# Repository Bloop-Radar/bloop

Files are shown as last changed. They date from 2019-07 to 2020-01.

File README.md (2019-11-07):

# Bloop Radar Platform

**Note: Hardware is still under heavy development. Please use at your own risk.**

## What is Bloop?
Bloop is an open-source 24 GHz radar platform aimed to be an easy way for hobbyists, students, and engineers to learn and experiment with radar. 

The goal for this project is not to make an application-specific radar but instead create a flexible platform to learn more about doppler and FMCW radar principles. In order to accomplish this the hardware must be low cost, modular, and allow people to develop their own applications easily. 

Currently, the software solution for Bloop is still unknown as the hardware is still being developed. The plan is to use the ECP5 as the FPGA for this platform and open-source FPGA toolchains available such as [Yosys](https://github.com/YosysHQ/yosys) and [nextpnr](https://github.com/YosysHQ/nextpnr).

## Hardware
The hardware will consist of three modules: an **antenna module** (work in progress), **RF module** ([BGT24 Module](#bgt24-module---rev-a)), and **digital module** (work in progress).

### Planned Hardware Specifications 
* 24 GHz Transceiver MMIC ([BGT24MTR12](https://www.infineon.com/cms/en/product/sensor/radar-image-sensors/radar-sensors/radar-sensors-for-consumer-and-iot/bgt24mtr12/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))
  * 1 TX SMP Connector
  * 2 RX SMP Connectors
* PLL with chirp generation ([LMX2491](http://www.ti.com/product/LMX2491))
* 4 Channel ADC ([ADAR7251](https://www.analog.com/en/products/adar7251.html#))
* ECP5 FPGA
* USB
* ... and more TBD

### BGT24 Module - Rev A
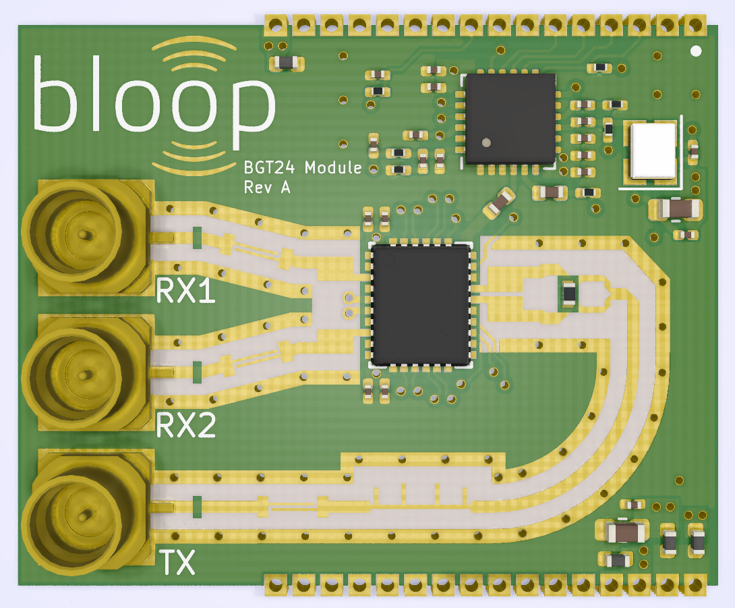
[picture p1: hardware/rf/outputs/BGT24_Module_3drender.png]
BGT24_Module_3drender
  

The BGT24 Module is the RF module for the Bloop radar platform, which provides differential I/Q data for RX1 and RX2 along with SPI and modulation control for the LMX2491 PLL and BGT24MTR12 RF transceiver. 

This module will continue to evolve as we test with the SPI Control prototyping hardware and develop some PCB antennas to test with.  

## Prototyping Hardware
Hardware found under `hardware/prototypes` is solely used to develop/evaluate the function of the RF section, BGT24 module, and the ADAR7251 ADC.

### SPI Control - Rev A
Work In Progress under branch `spi_control`  

The SPI Control hardware will include a USB-SPI controller for evaluating the BGT24 Module and ADC. The board will also include an external connector to interface with FPGA development boards.

### RF Front-End - Rev A
The RF Front-End is a panel of various RF microstrip structures to be evaluated for the RF section.

## License
Bloop hardware is distributed under the [Creative Commons Attribution Share Alike 4.0 International](LICENSE.txt)

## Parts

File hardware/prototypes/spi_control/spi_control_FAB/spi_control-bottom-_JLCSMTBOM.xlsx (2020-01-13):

Comment | Designator | Footprint | Description
100n | C21, C33, C37, C38, C39, C40, C42, C43 | C_0402_1005Metric | CAP CER 0.1UF 6.3V X5R 0402
1n | C44 | C_0402_1005Metric | CAP CER 1000PF 50V X7R 0402
100p | C1 | C_0402_1005Metric | CAP CER 100PF 50V C0G/NP0 0402
10u | C22, C28, C30, C32, C34, C35, C36 | C_0402_1005Metric | CAP CER 10UF 6.3V X6S 0402
12p | C18, C23 | C_0402_1005Metric | CAP CER 12PF 50V C0G/NP0 0402
1u | C3, C19 | C_0402_1005Metric | CAP CER 1UF 6.3V X5R 0402
390p | C29 | C_0402_1005Metric | CAP CER 390PF 50V X7R 0402
4.7u | C2, C4 | C_0402_1005Metric | CAP CER 4.7UF 6.3V X5R 0402
5.6n | C27 | C_0402_1005Metric | CAP CER 5600PF 25V X7R 0402
10k | R9, R11, R12 | R_0402_1005Metric | RES SMD 10K OHM 1% 1/16W 0402
1k | R4, R10 | R_0402_1005Metric | RES SMD 1K OHM 1% 1/16W 0402
1M | R1 | R_0402_1005Metric | RES SMD 1M OHM 1% 1/16W 0402
330 | R3, R8 | R_0402_1005Metric | RES SMD 330 OHM 1% 1/16W 0402
820 | R2 | R_0402_1005Metric | RES SMD 820 OHM 5% 1/16W 0402
SP0503BAHTG | D1 | SOT-143 | TVS DIODE 5.5V 8.5V SOT143-4
MCP2210-I_MQ | U3 | QFN-20-1EP_5x5mm_P0.65mm_EP3.35x3.35mm | IC CONVERTER USB-SPI 20-QFN
ST1L08SPU33R | U2 | DFN-8-1EP_2x3mm_P0.5mm_EP0.61x2.2mm | IC REG LINEAR 3.3V 800MA 8DFN
12MHZ | Y1 | Crystal_SMD_Abracon_ABM8G-4Pin_3.2x2.5mm | CRYSTAL 12MHZ 12PF SMD
1k | FB1, FB2 | L_0603_1608Metric | FERRITE BEAD 1 KOHM 0603 1LN
Versa_2 | J2 | PinSocket_2x20_P2.54mm_Vertical_SMD | CONN HDR 40POS 0.1 TIN SMD
Versa_1 | J3 | PinSocket_2x20_P2.54mm_Vertical_SMD | CONN HDR 40POS 0.1 TIN SMD
USB_B_Micro | J1 | USB_Micro-B_Molex_47346-0001 | CONN RCPT USB2.0 MICRO B SMD R/A

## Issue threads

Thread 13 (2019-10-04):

Select and implement low noise power circuit on SPI controller prototype

leoleal3, 2019-10-04:
Need to find a low noise LDO for 3.3V output for the PLL and RF MMIC

leoleal3, 2019-10-13:
Selected and implemented ST1L08SPU33R for the SPI controller prototype board in 42bd93bd553da56d5092573edd4d9227b1fe1c8b.
In the future I think we will want separate LDOs for specific parts.

Closed 2019-10-13.

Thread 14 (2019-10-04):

Select and implement SPI controller for SPI_controller prototype

leoleal3, 2019-10-04:

leoleal3, 2019-10-13:
Selected MCP2210-L/MQ and implemented in schematic here: ad3a562a2b1e13b54f219fbda9ca29bfedb54d95

Closed 2019-10-13.

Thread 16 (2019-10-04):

Design LMX2491 PLL loop filter

roguepengu1n, 2019-10-04:

roguepengu1n, 2019-11-04:
For now, we are going to use the loop filter part values used in the [Infineon Position2Go](https://www.infineon.com/cms/en/product/evaluation-boards/demo-position2go/). During testing of the module, we can experiment with changing values based on the [TI PLLatinum simulation tool](http://www.ti.com/tool/PLLATINUMSIM-SW).

Closed 2019-11-04.

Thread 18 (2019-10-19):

Select a connector for the external IO on the SPI control board

roguepengu1n, 2019-10-19:
Need a connector to interface with the ADC and allow the use of external FPGA/SoC dev boards to interface with. Possibly a PMOD interface?

roguepengu1n, 2019-11-11:
Going with two 2x20 female 2.54mm pin headers that will interface with the [ECP5 Evaluation Board](http://www.latticesemi.com/ecp5-evaluation) Vera Header from Lattice.

Closed 2019-11-11.

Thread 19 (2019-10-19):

Add BGT24 Module symbol and footprint

roguepengu1n, 2019-10-19:
Need a symbol and footprint for the BGT24 Module revA board to use in the SPI control board

roguepengu1n, 2019-11-04:
Added symbol and footprint in 3aa3cebe3509e6f3966daaffc69ec17ca2079d38

Closed 2019-11-04.

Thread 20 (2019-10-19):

SPI control board layout

roguepengu1n, 2019-10-19:
Layout of the SPI control prototyping board

roguepengu1n, 2019-11-18:
Layout completed by @kishan118 a3565c40fd2059d0a1c43607e4b8c9b3cc40f425.
Review of layout to be completed next.

Closed 2019-11-18.

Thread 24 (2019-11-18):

SPI_Control Layout Review

roguepengu1n, 2019-11-18:
Review conducted on spi_control commit a3565c40fd2059d0a1c43607e4b8c9b3cc40f425.

**Findings from review to be implemented:**

1. Remove "dime for scale" from ECO layer.
2. Fill on Top layer has no net, set to GND.
3. Fill on Bottom layer has no net set to GND.
4. Schematic: Clean up the ground connections on J40, J39, Y2, and Y1.
5. Schematic: Remove ECP5 eval board schematic image.
6. Need to generate HTML BOM.
7. Schematic: Add NC to J1 and J2 where needed.
8. Change directory “gerbers” to “spi_control_FAB”
9. Add 3d model for Y1?
10. Add vias to isolated island fills.
11. Add higher-priority zone for U3.
12. Add pin one indicators to J39 and J40 silkscreen.
13. Double-check via annular ring; does it support JLC’s fab requirements?
14. Center layout in .kicad_pcb file.
15. Add “Rev A” to silkscreen.
16. Use the /lib/bloop.kicad_wks file for the .kicad_pcb file.
17. Add LED silkscreen labels.
18. Add standoffs to schematic (to be tracked by BOM).
19. Add OSHW logo.
20. Set mounting holes to GND.
21. Schematic: Add typical current draw for ADAR7251 and maybe BG24 Module.
22. Select Ferrite bead MPNs
23. Try to condense MPNs to common MPNs across BGT24 module (reference: bloop/hardware/rf/bom)
24. Schematic: move dashed line box over ADC input filter caps to right so that it doesn’t interfere with labels. Change comment to “Redundant filtering if necessary” or something.
25. Generate PDF output files of schematic and PCB.

**Additional Notes:**
- Consider alignment pin in order to keep the BGT24 module aligned with the SPI board and antenna board.
- BGT24 Module 3d model is crooked. Will fix in: https://github.com/Bloop-Radar/bloop/issues/23

Closed 2020-01-05.

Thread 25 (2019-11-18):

Tent vias in BGT24 Module FAB files

roguepengu1n, 2019-11-18:
Vias should be tented with mask on BGT24 Module to prevent shorts on base-board that it mates with.

Closed 2019-11-21.

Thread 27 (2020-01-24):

Incorrect footprint for U2 ST1L08SPU33R on SPI Control Board Rev A

roguepengu1n, 2020-01-24:
Current footprint is: Package_DFN_QFN:DFN-8-1EP_2x3mm_P0.5mm_EP0.61x2.2mm
Should be: Package_DFN_QFN:DFN-8-1EP_3x2mm_P0.5mm_EP1.3x1.5mm

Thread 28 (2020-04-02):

Incorrect footprint for micro-USB connector J1 on SPI Control Board Rev A

roguepengu1n, 2020-04-02:
Footprint does not match the MPN footprint ([10118193-0001LF](https://www.amphenol-icc.com/media/wysiwyg/files/drawing/10118193.pdf)).
The footprint in the layout is a completely SMD footprint while the MPN has THT shield pins.

Change J1 footprint to correct MPN footprint.

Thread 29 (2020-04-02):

Add solder mask to TX and RX pads on BGT24MTR12 footprint

roguepengu1n, 2020-04-02:
To prevent solder from flowing along the transmission lines, add solder mask to spacing for pads 22, 23, 3, and 8.

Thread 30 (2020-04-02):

bloop.dcm causing warnings when opening schematics

roguepengu1n, 2020-04-02:
Error message appears when opening schematics:

```
9:28:18 PM: Symbol name conflict in library:
C:\Projects\bloop\hardware\prototypes\spi_control/../../lib/bloop.lib
'BGT24_Module_Castellations' has been renamed to 'BGT24_Module_Castellations_0'
9:28:18 PM: Symbol name conflict in library:
C:\Projects\bloop\hardware\prototypes\spi_control/../../lib/bloop.lib
'ECS-2520S' has been renamed to 'ECS-2520S_0'
9:28:18 PM: Symbol name conflict in library:
C:\Projects\bloop\hardware\prototypes\spi_control/../../lib/bloop.lib
'GNDRF' has been renamed to 'GNDRF_0'
9:28:18 PM: Alias 'KC3225K40' not found in library: 'C:\Projects\bloop\hardware\prototypes\spi_control\..\..\lib\bloop.dcm'

```

Most likely because bloop.dcm got added when the spi_control branch was merged.

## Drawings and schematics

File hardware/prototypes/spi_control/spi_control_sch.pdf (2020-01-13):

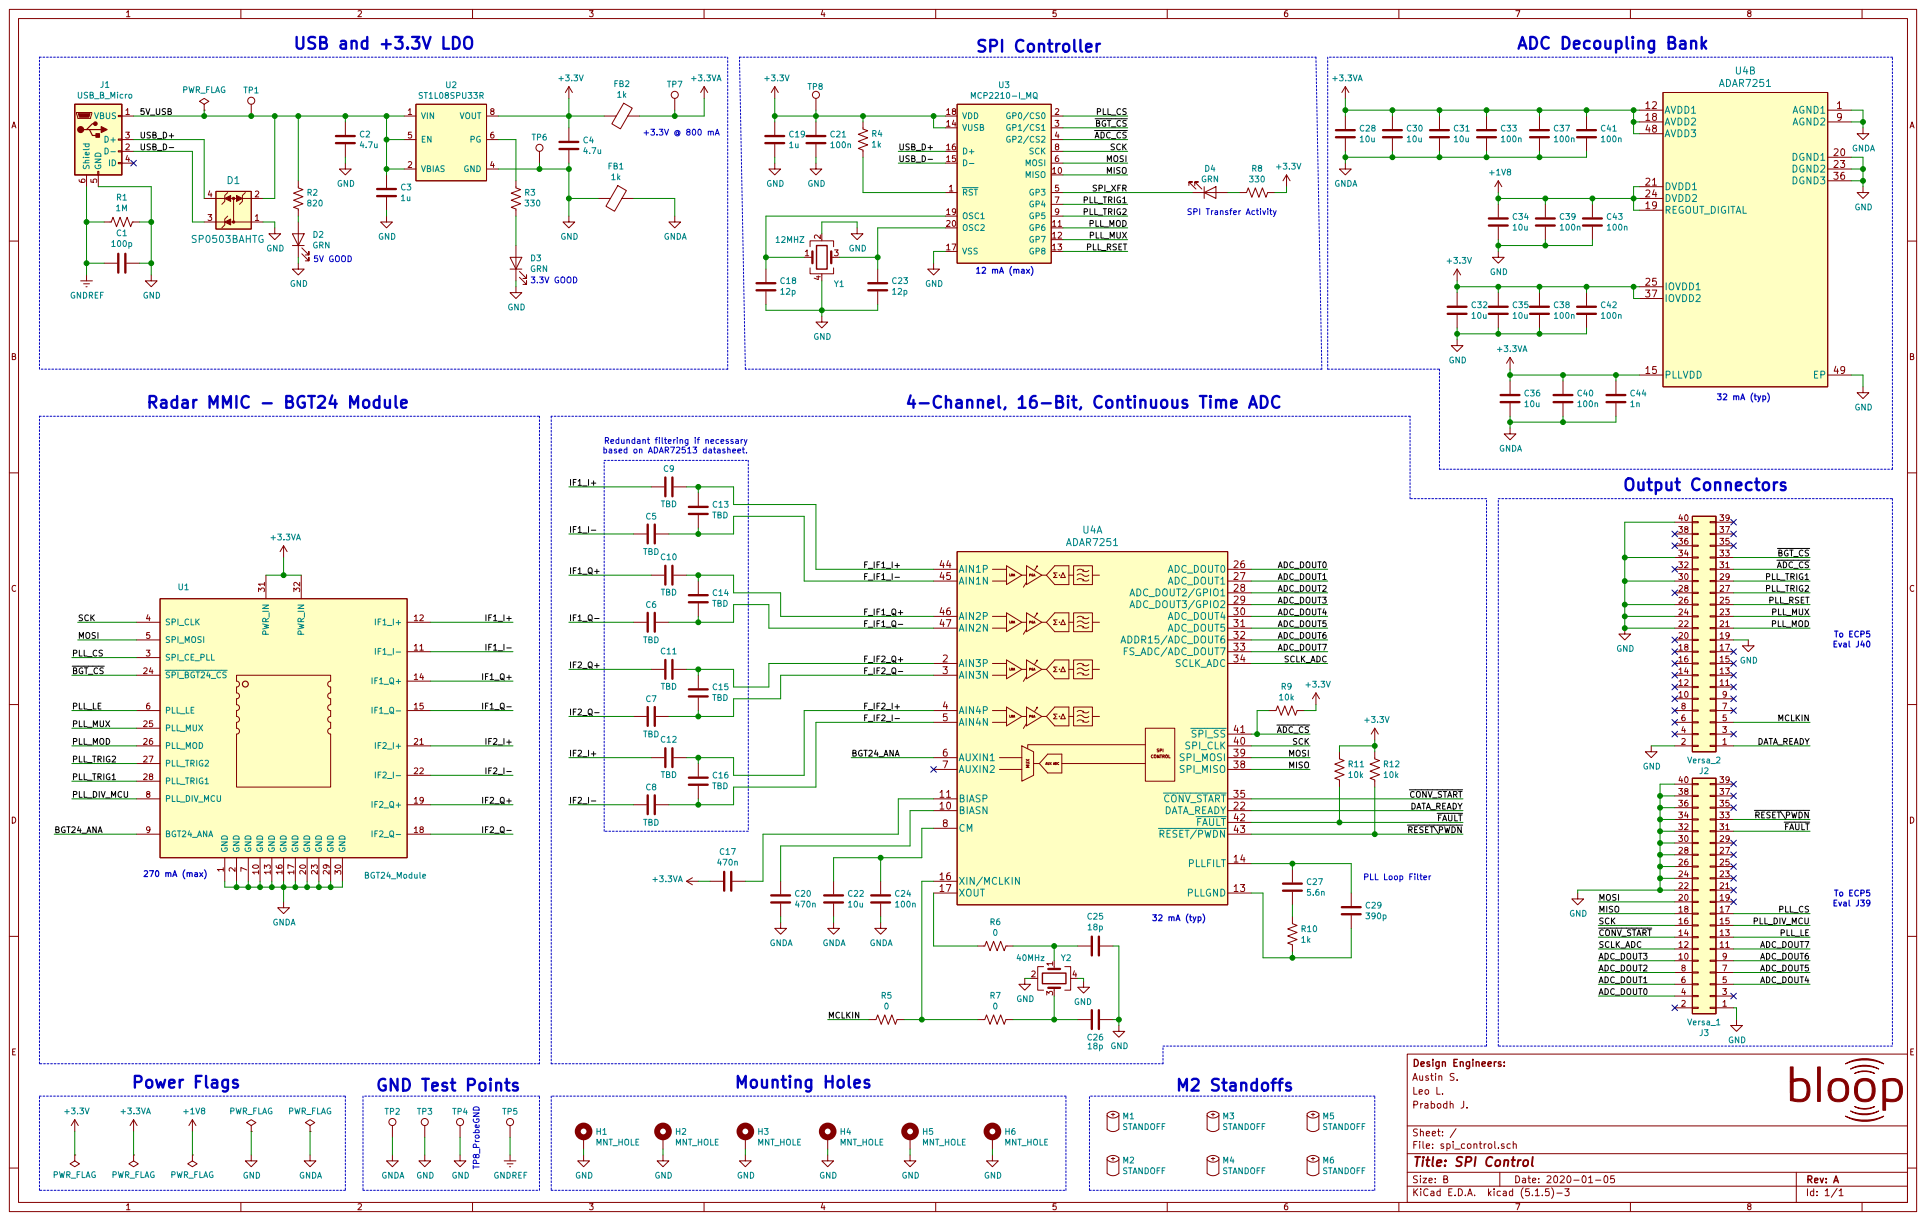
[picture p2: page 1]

4-Channel, 16-Bit, Continuous Time ADC

Redundant filtering if necessary based on ADAR72513 datasheet.
C9 TBD

ADAR7251
File: spi_control.sch Sheet: / Prabodh J. Leo L. Austin S. Design Engineers: R9

24 | 23 PLL_MUX
22 | 21

32 | 31
30 | 29 PLL_CS
28 | 27
26 | 25
24 | 23

Id: 1/1 Title: SPI Control

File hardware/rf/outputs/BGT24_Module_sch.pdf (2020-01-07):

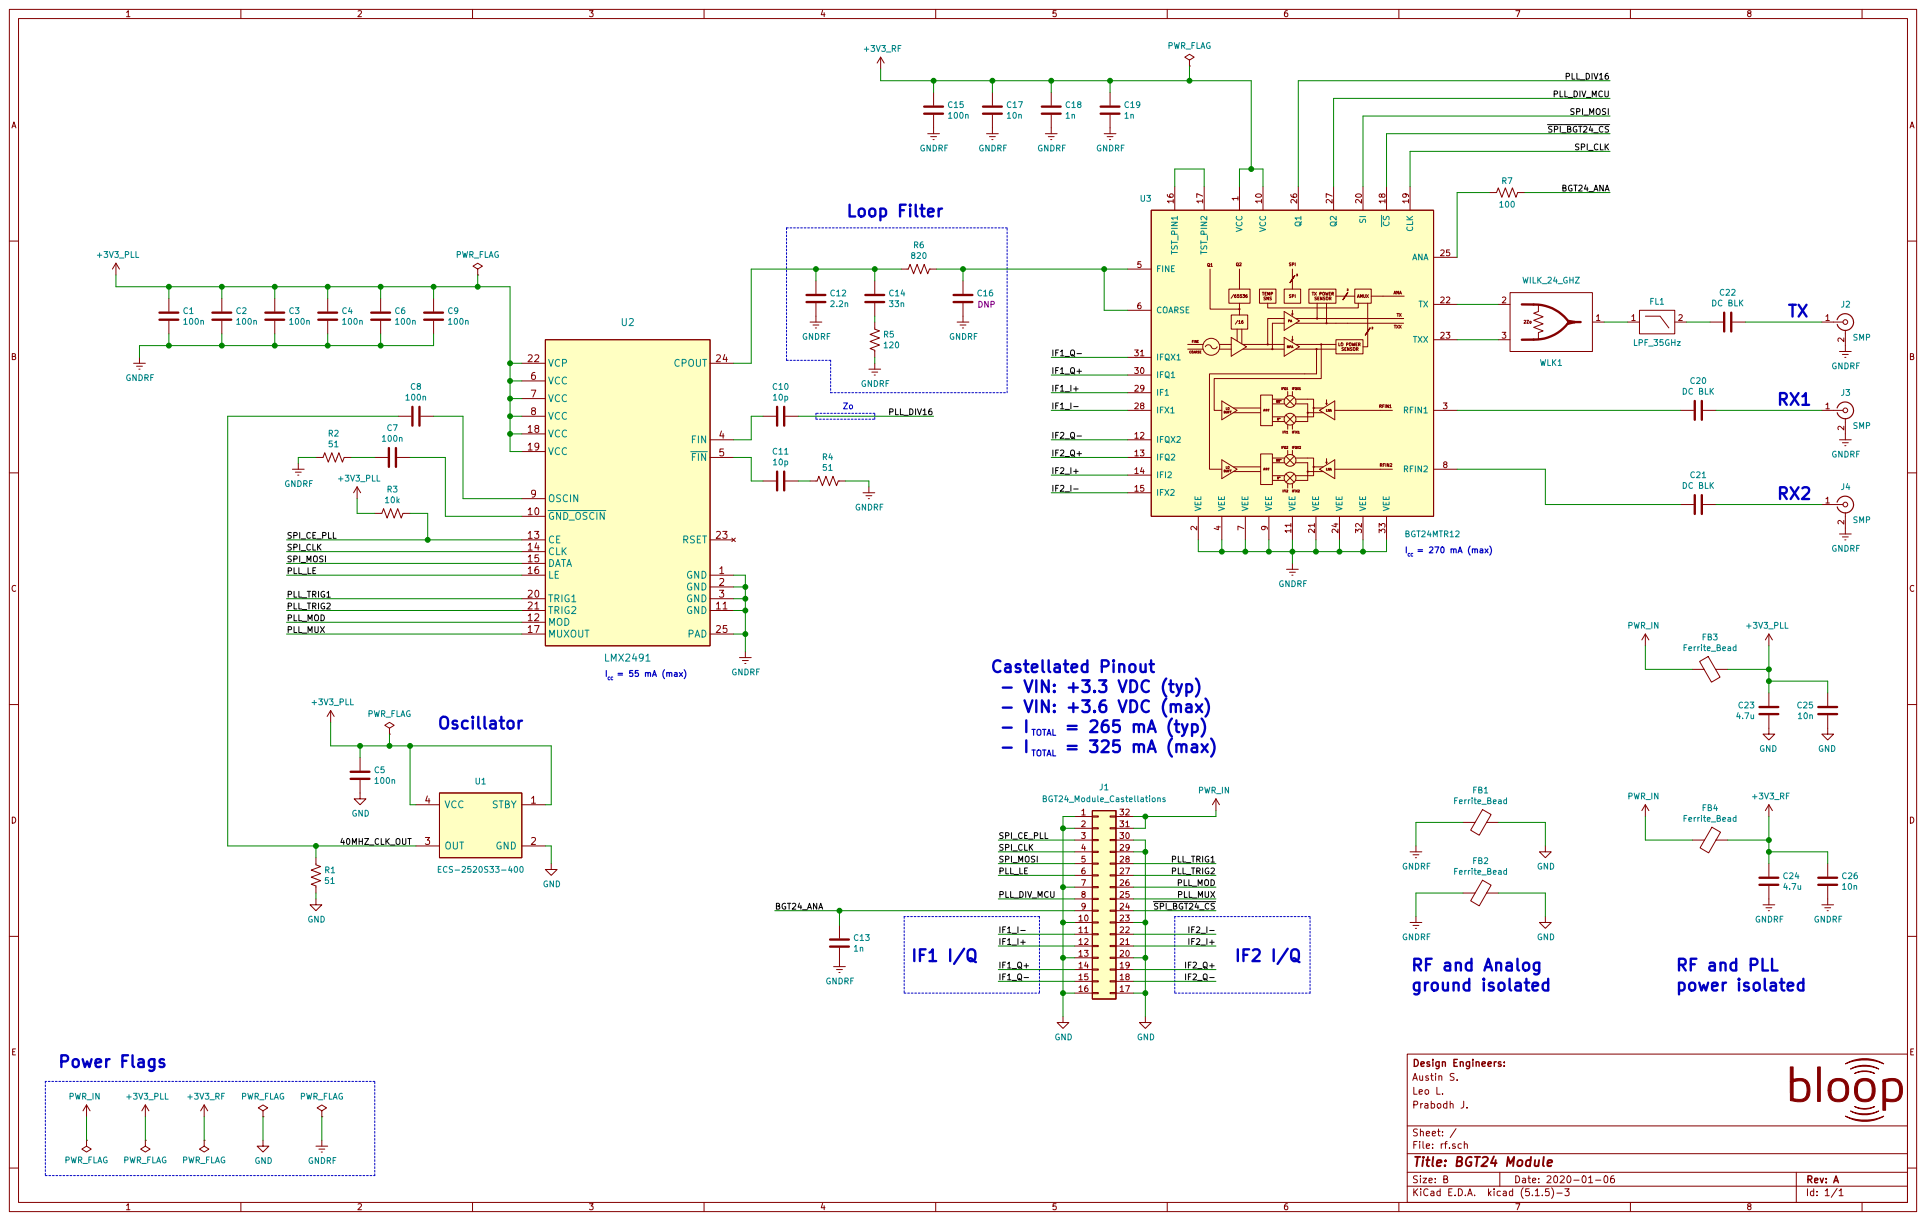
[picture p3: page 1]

2 SI 20 VEE 21 TX 22 TXX 23 VEE 24 ANA 25 Q1 26 Q2 27

LO POWER MPA

GNDRF GNDRF

2 | 31
3 4 5 6 7 | 30

10 | | 23
11 12 13 | | 22

21 | | IF2_I+
20 | | IF2_Q+

File: rf.sch Sheet: / Prabodh J. Leo L. Austin S. Design Engineers:

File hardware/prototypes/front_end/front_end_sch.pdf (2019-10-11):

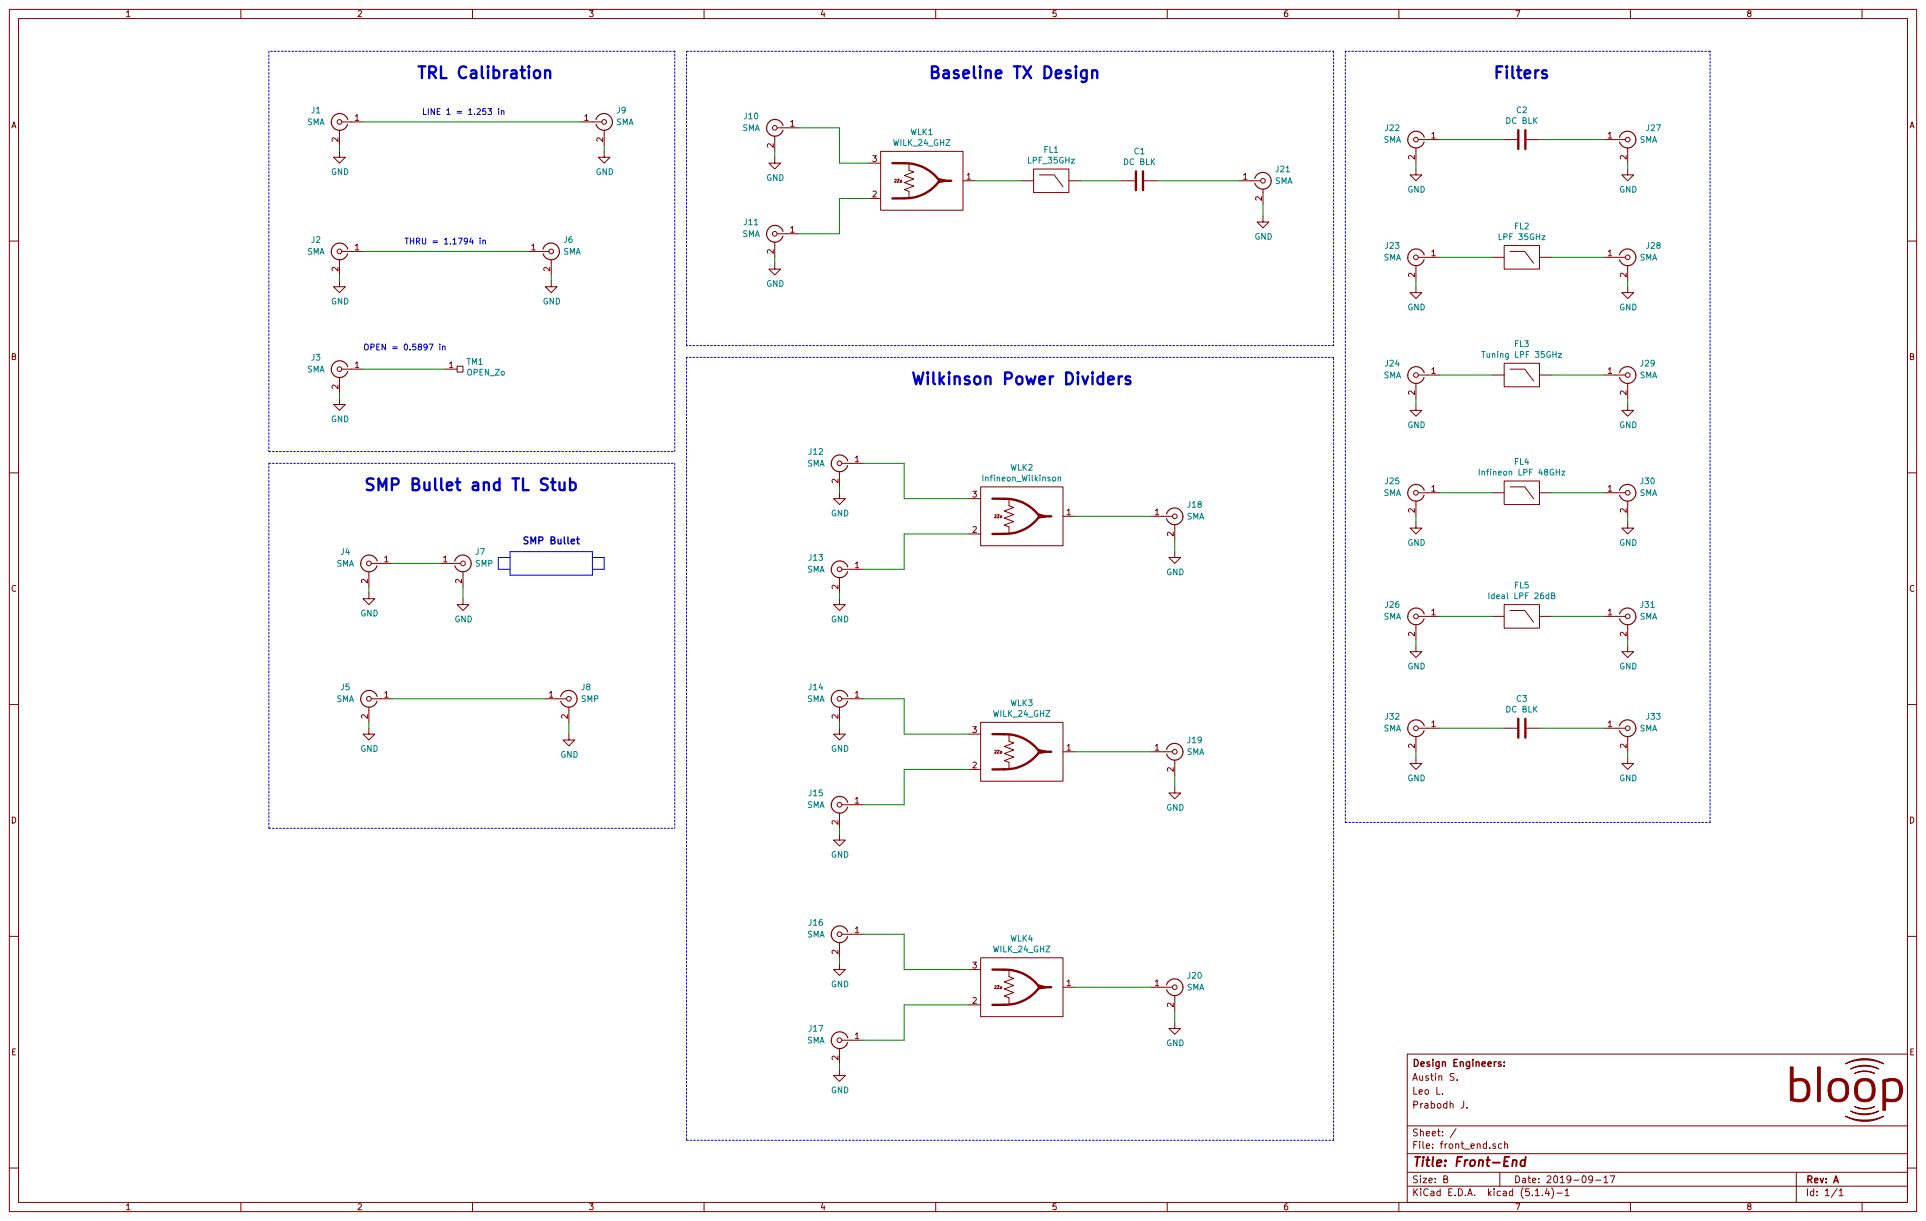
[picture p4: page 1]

LINE 1 = 1.253 in SMP Bullet and TL Stub
J3 SMA GND 1 2

File: front_end.sch Sheet: / Prabodh J. Leo L. Austin S. Design Engineers:

Id: 1/1 Title: Front-End

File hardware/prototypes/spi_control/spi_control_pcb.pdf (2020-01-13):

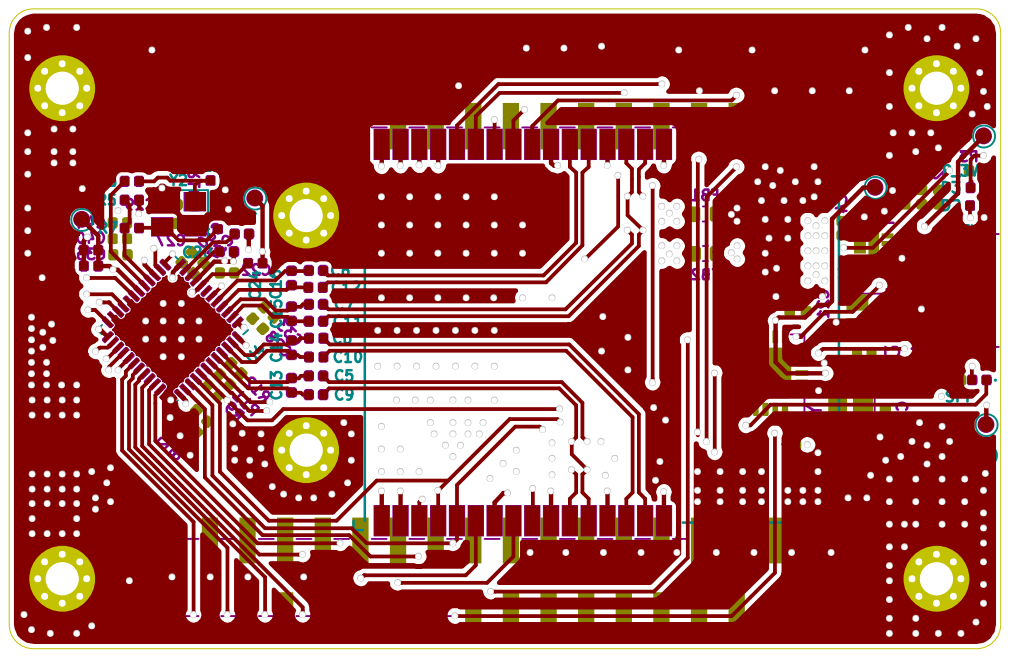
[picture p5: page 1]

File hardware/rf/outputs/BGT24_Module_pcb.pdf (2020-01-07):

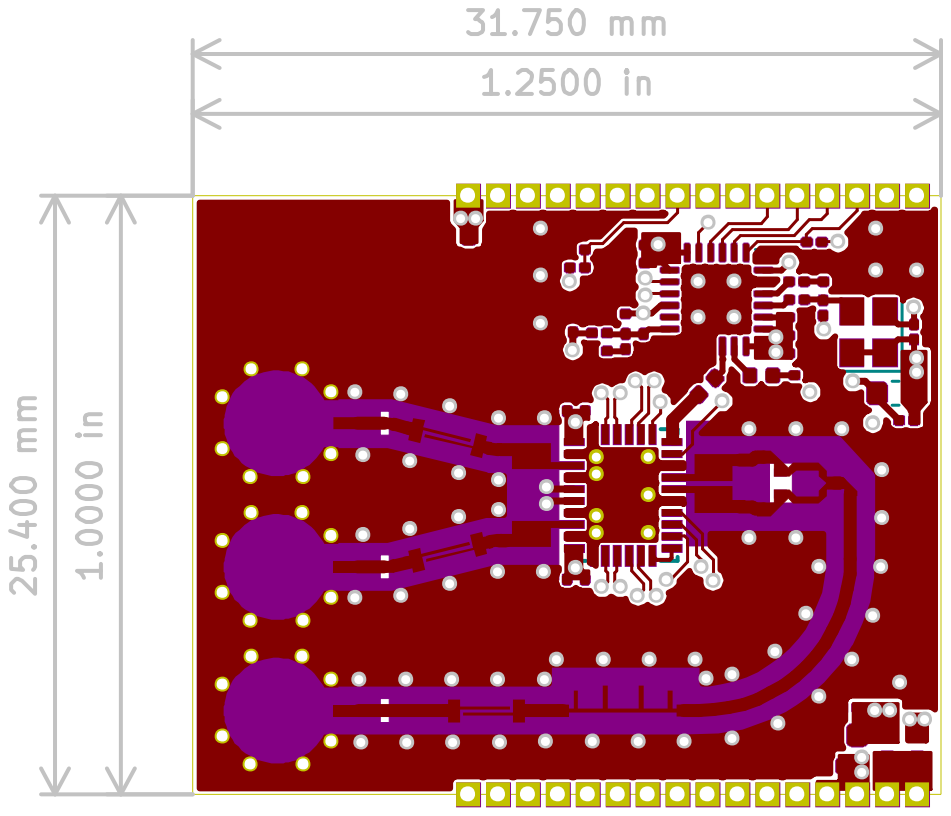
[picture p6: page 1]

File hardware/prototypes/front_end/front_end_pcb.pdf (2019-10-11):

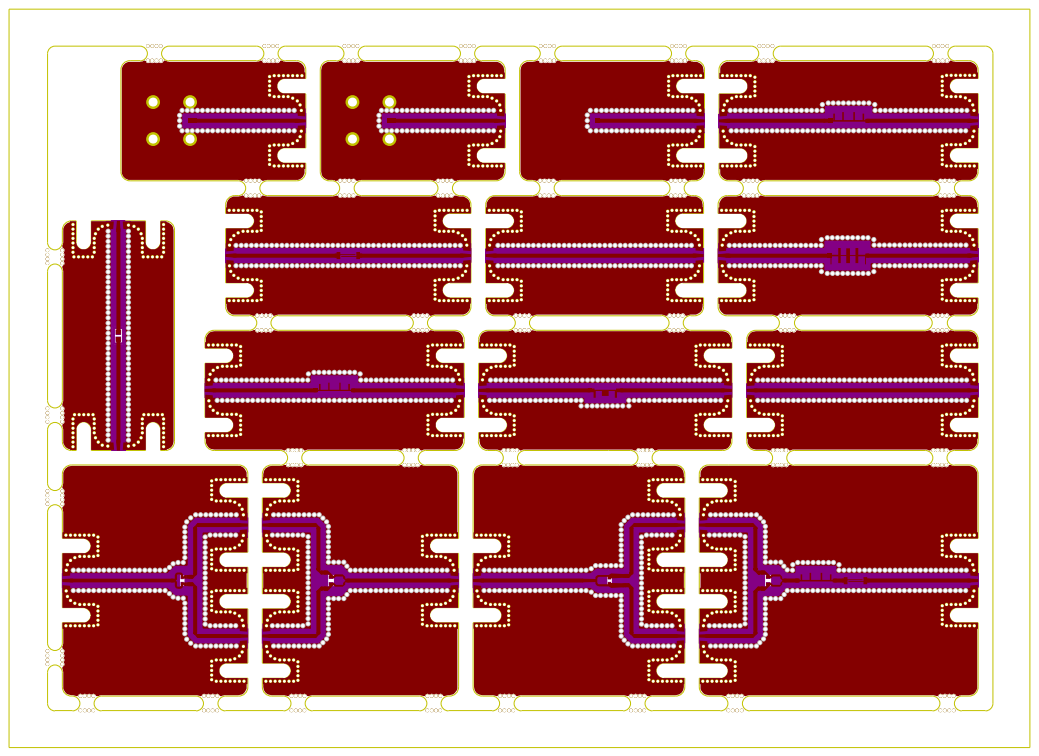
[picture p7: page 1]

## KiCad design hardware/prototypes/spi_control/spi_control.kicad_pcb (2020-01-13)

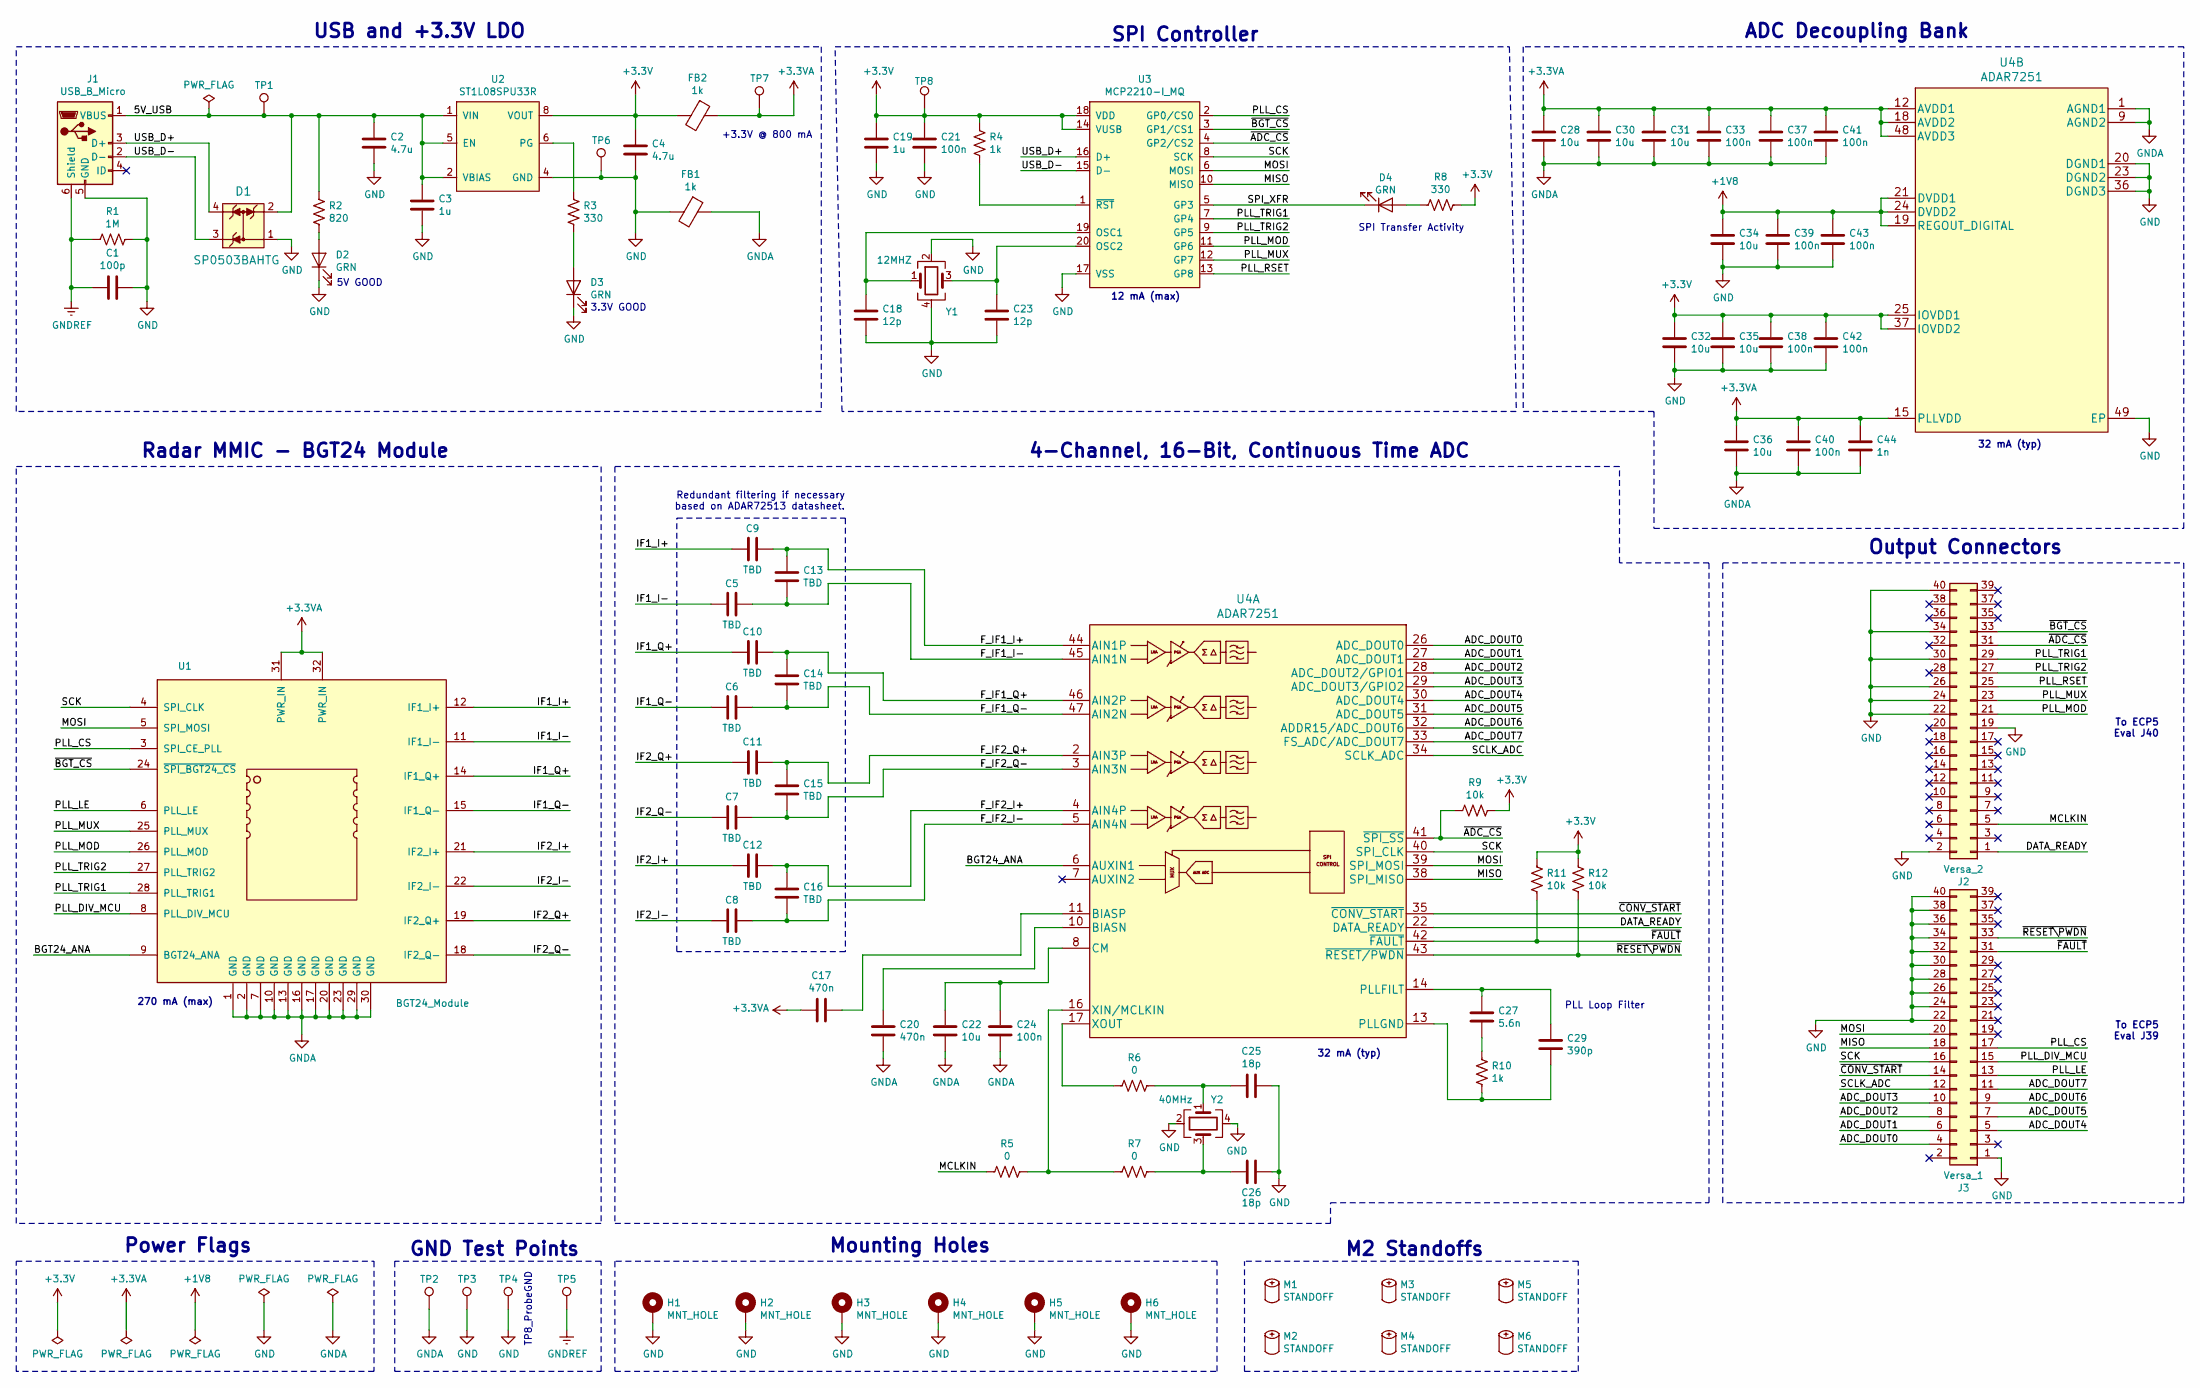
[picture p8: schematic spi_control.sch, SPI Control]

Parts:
C1: 100p; C_0402_1005Metric; MPN GCM1555C1H101JA16D; Digi-Key_PN 490-10669-1-ND
C2, C4: 4.7u; C_0402_1005Metric; MPN GRM155R60J475ME47D; Digi-Key_PN 490-5915-1-ND
C3, C19: 1u; C_0402_1005Metric; MPN CL05A105MQ5NNNC; Digi-Key_PN 1276-1235-1-ND
C5, C6, C7, C8, C9, C10, C11, C12, C13, C14, C15, C16: TBD; C_0402_1005Metric
C17, C20: 470n; C_0402_1005Metric; MPN CL05A474KQ5NNNC; Digi-Key_PN 1276-1479-1-ND
C18, C23: 12p; C_0402_1005Metric; MPN C0402C120J5GACTU; Digi-Key_PN 399-1013-1-ND
C21, C24, C33, C37, C38, C39, C40, C41, C42, C43: 100n; C_0402_1005Metric; MPN CL05A104KQ5NNNC; Digi-Key_PN 1276-1442-1-ND
C22, C28, C30, C31, C32, C34, C35, C36: 10u; C_0402_1005Metric; MPN GRM155C80J106ME11D; Digi-Key_PN 490-13233-1-ND
C25, C26: 18p; C_0402_1005Metric; MPN 04025A180JAT2A; Digi-Key_PN 478-1073-1-ND
C27: 5.6n; C_0402_1005Metric; MPN CL05B562KA5NNNC; Digi-Key_PN 1276-1578-1-ND
C29: 390p; C_0402_1005Metric; MPN CL05B391KB5NNNC; Digi-Key_PN 1276-1560-1-ND
C44: 1n; C_0402_1005Metric; MPN C0402C102K5RACTU; Digi-Key_PN 399-1032-1-ND
D1: SP0503BAHTG; SOT-143; MPN SP0503BAHTG; Digi-Key_PN F2715CT-ND
D2, D3, D4: GRN; LED_0402_1005Metric; MPN SML-P13PTT86R; Digi-Key_PN 846-1197-1-ND
FB1, FB2: 1k; L_0603_1608Metric; MPN 742792662; Digi-Key_PN 732-4670-1-ND
H1, H2, H3, H4, H5, H6: MNT_HOLE; MountingHole_2.2mm_M2_Pad_Via
J1: USB_B_Micro; USB_Micro-B_Molex_47346-0001; MPN 10118193-0001LF; Digi-Key_PN 609-4616-1-ND
J2: Versa_2; PinSocket_2x20_P2.54mm_Vertical_SMD; MPN NPTC202KFMS-RC; Digi-Key_PN S5690-ND
J3: Versa_1; PinSocket_2x20_P2.54mm_Vertical_SMD; MPN NPTC202KFMS-RC; Digi-Key_PN S5690-ND
M1, M2, M3, M4, M5, M6: STANDOFF; MPN 970120244; Digi-Key_PN 732-12852-ND
R1: 1M; R_0402_1005Metric; MPN RC0402FR-071ML; Digi-Key_PN 311-1.00MLRCT-ND
R2: 820; R_0402_1005Metric; MPN RC0402JR-07820RL; Digi-Key_PN 311-820JRCT-ND
R3, R8: 330; R_0402_1005Metric; MPN RC0402FR-07330RL; Digi-Key_PN 311-330LRCT-ND
R4, R10: 1k; R_0402_1005Metric; MPN RC0402FR-071KL; Digi-Key_PN 311-1.00KLRCT-ND
R5, R6, R7: 0; R_0402_1005Metric; MPN RC0402JR-070RL; Digi-Key_PN 311-0.0JRCT-ND
R9, R11, R12: 10k; R_0402_1005Metric; MPN RC0402FR-0710KL; Digi-Key_PN 311-10.0KLRCT-ND
TP1, TP2, TP3, TP5, TP6, TP7, TP8: TestPoint; TestPoint_Pad_D1.0mm
TP4: TestPoint; TestPoint_Keystone_5019_Minature; MPN 5019; Digi-Key_PN 36-5019CT-ND
U1: BGT24_Module
U2: ST1L08SPU33R; DFN-8-1EP_2x3mm_P0.5mm_EP0.61x2.2mm; MPN ST1L08SPU33R; Digi-Key_PN 497-15508-1-ND
U3: MCP2210-I_MQ; QFN-20-1EP_5x5mm_P0.65mm_EP3.35x3.35mm; MPN MCP2210-I/MQ; Digi-Key_PN MCP2210-I/MQ-ND
U4: ADAR7251; LFCSP-48-1EP_7x7mm_P0.5mm_EP4.1x4.1mm; MPN ADAR7251WBCSZ; Digi-Key_PN ADAR7251WBCSZ-ND
Y1: 12MHZ; Crystal_SMD_Abracon_ABM8G-4Pin_3.2x2.5mm; MPN ECS-120-12-33-AGN-TR; Digi-Key_PN XC2611CT-ND
Y2: 40MHz; Crystal_SMD_Abracon_ABM8G-4Pin_3.2x2.5mm; MPN ECS-400-18-33-JGN-TR; Digi-Key_PN XC2717CT-ND

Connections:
+1V8: C34.1, C39.1, C43.1, U4.19 (REGOUT_DIGITAL), U4.21 (DVDD1), U4.24 (DVDD2)
+3.3VA: C17.2, C28.1, C30.1, C31.1, C33.1, C36.1, C37.1, C40.1, C41.1, C44.1, FB2.1, TP7.1, U1.31 (PWR_IN), U1.32 (PWR_IN), U4.12 (AVDD1), U4.15 (PLLVDD), U4.18 (AVDD2), U4.48 (AVDD3)
+3V3: C4.1, C19.1, C21.1, C32.1, C35.1, C38.1, C42.1, FB2.2, R4.2, R8.1, R9.1, R11.1, R12.1, TP8.1, U2.8 (VOUT), U3.14 (VUSB), U3.18 (VDD), U4.25 (IOVDD1), U4.37 (IOVDD2)
/5V_USB: C2.1, C3.1, D1.2, J1.1 (VBUS), R2.2, TP1.1, U2.1 (VIN), U2.2 (VBIAS), U2.5 (EN)
/ADC_DOUT0: J3.4, U4.26 (ADC_DOUT0)
/ADC_DOUT1: J3.6, U4.27 (ADC_DOUT1)
/ADC_DOUT2: J3.8, U4.28 (ADC_DOUT2/GPIO1)
/ADC_DOUT3: J3.10, U4.29 (ADC_DOUT3/GPIO2)
/ADC_DOUT4: J3.5, U4.30 (ADC_DOUT4)
/ADC_DOUT5: J3.7, U4.31 (ADC_DOUT5)
/ADC_DOUT6: J3.9, U4.32 (ADDR15/ADC_DOUT6)
/ADC_DOUT7: J3.11, U4.33 (FS_ADC/ADC_DOUT7)
/BGT24_ANA: U1.9 (BGT24_ANA), U4.6 (AUXIN1)
/DATA_READY: J2.1, U4.22 (DATA_READY)
/F_IF1_I+: C9.2, C13.2, U4.44 (AIN1P)
/F_IF1_I-: C5.2, C13.1, U4.45 (AIN1N)
/F_IF1_Q+: C10.2, C14.2, U4.46 (AIN2P)
/F_IF1_Q-: C6.2, C14.1, U4.47 (AIN2N)
/F_IF2_I+: C12.2, C16.2, U4.4 (AIN4P)
/F_IF2_I-: C8.2, C16.1, U4.5 (AIN4N)
/F_IF2_Q+: C11.2, C15.2, U4.2 (AIN3P)
/F_IF2_Q-: C7.2, C15.1, U4.3 (AIN3N)
/IF1_I+: C9.1, U1.12 (IF1_I+)
/IF1_I-: C5.1, U1.11 (IF1_I-)
/IF1_Q+: C10.1, U1.14 (IF1_Q+)
/IF1_Q-: C6.1, U1.15 (IF1_Q-)
/IF2_I+: C12.1, U1.21 (IF2_I+)
/IF2_I-: C8.1, U1.22 (IF2_I-)
/IF2_Q+: C11.1, U1.19 (IF2_Q+)
/IF2_Q-: C7.1, U1.18 (IF2_Q-)
/MCLKIN: J2.5, R5.2
/MISO: J3.18, U3.10 (MISO), U4.38 (SPI_MISO)
/MOSI: J3.20, U1.5 (SPI_MOSI), U3.6 (MOSI), U4.39 (SPI_MOSI)
/PLL_CS: J3.17, U1.3 (SPI_CE_PLL), U3.2 (GP0/CS0)
/PLL_DIV_MCU: J3.15, U1.8 (PLL_DIV_MCU)
/PLL_LE: J3.13, U1.6 (PLL_LE)
/PLL_MOD: J2.21, U1.26 (PLL_MOD), U3.11 (GP6)
/PLL_MUX: J2.23, U1.25 (PLL_MUX), U3.12 (GP7)
/PLL_RSET: J2.25, U3.13 (GP8)
/PLL_TRIG1: J2.29, U1.28 (PLL_TRIG1), U3.7 (GP4)
/PLL_TRIG2: J2.27, U1.27 (PLL_TRIG2), U3.9 (GP5)
/SCK: J3.16, U1.4 (SPI_CLK), U3.8 (SCK), U4.40 (SPI_CLK)
/SCLK_ADC: J3.12, U4.34 (SCLK_ADC)
/SPI_XFR: D4.1 (K), U3.5 (GP3)
/USB_D+: D1.4, J1.3 (D+), U3.16 (D+)
/USB_D-: D1.3, J1.2 (D-), U3.15 (D-)
/~ADC_CS: J2.31, R9.2, U3.4 (GP2/CS2), U4.41 (~SPI_SS)
/~BGT_CS: J2.33, U1.24 (~SPI_BGT24_CS), U3.3 (GP1/CS1)
/~CONV_START: J3.14, U4.35 (~CONV_START)
/~FAULT: J3.31, R11.2, U4.42 (~FAULT)
/~RESET\PWDN: J3.33, R12.2, U4.43 (~RESET/PWDN)
GND: C1.2, C2.2, C3.2, C4.2, C18.1, C19.2, C21.2, C23.1, C25.1, C26.1, C32.2, C34.2, C35.2, C38.2, C39.2, C42.2, C43.2, D1.1, D2.1 (K), D3.1 (K), FB1.2, H1.1, H2.1, H3.1, H4.1, H5.1, H6.1, J1.5 (GND), J2.2, J2.19, J2.22, J2.24, J2.26, J2.30, J2.34, J2.40, J3.1, J3.22, J3.24, J3.26, J3.28, J3.30, J3.32, J3.34, J3.36, J3.38, J3.40, R1.2, TP3.1, TP4.1, TP6.1, U2.4 (GND), U3.17 (VSS), U4.20 (DGND1), U4.23 (DGND2), U4.36 (DGND3), U4.49 (EP), Y1.2, Y1.4, Y2.2, Y2.4
GNDA: C20.2, C22.2, C24.2, C28.2, C30.2, C31.2, C33.2, C36.2, C37.2, C40.2, C41.2, C44.2, FB1.1, TP2.1, U1.1 (GND), U1.2 (GND), U1.7 (GND), U1.10 (GND), U1.13 (GND), U1.16 (GND), U1.17 (GND), U1.20 (GND), U1.23 (GND), U1.29 (GND), U1.30 (GND), U4.1 (AGND1), U4.9 (AGND2)
GNDREF: C1.1, J1.6 (Shield), R1.1, TP5.1
unnamed: C17.1, U4.11 (BIASP)
unnamed: C18.2, U3.19 (OSC1), Y1.1
unnamed: C20.1, U4.10 (BIASN)
unnamed: C22.1, C24.1, U4.8 (CM)
unnamed: C23.2, U3.20 (OSC2), Y1.3
unnamed: C25.2, R6.1, Y2.1
unnamed: C26.2, R7.1, Y2.3
unnamed: C27.1, C29.1, U4.14 (PLLFILT)
unnamed: C27.2, R10.1
unnamed: C29.2, R10.2, U4.13 (PLLGND)
unnamed: D2.2 (A), R2.1
unnamed: D3.2 (A), R3.1
unnamed: D4.2 (A), R8.2
unnamed: R3.2, U2.6 (PG)
unnamed: R4.1, U3.1 (~RST)
unnamed: R5.1, R7.2, U4.16 (XIN/MCLKIN)
unnamed: R6.2, U4.17 (XOUT)

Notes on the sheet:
5V GOOD
3.3V GOOD
SPI Controller
USB and +3.3V LDO
PLL Loop Filter
Power Flags
12 mA (max)
ADC Decoupling Bank
Output Connectors
SPI Transfer Activity
4-Channel, 16-Bit, Continuous Time ADC
GND Test Points
Redundant filtering if necessary based on ADAR72513 datasheet.
Radar MMIC - BGT24 Module
TP8_ProbeGND
Mounting Holes
32 mA (typ)
M2 Standoffs
270 mA (max)
+3.3V @ 800 mA
To ECP5 Eval J40
To ECP5 Eval J39

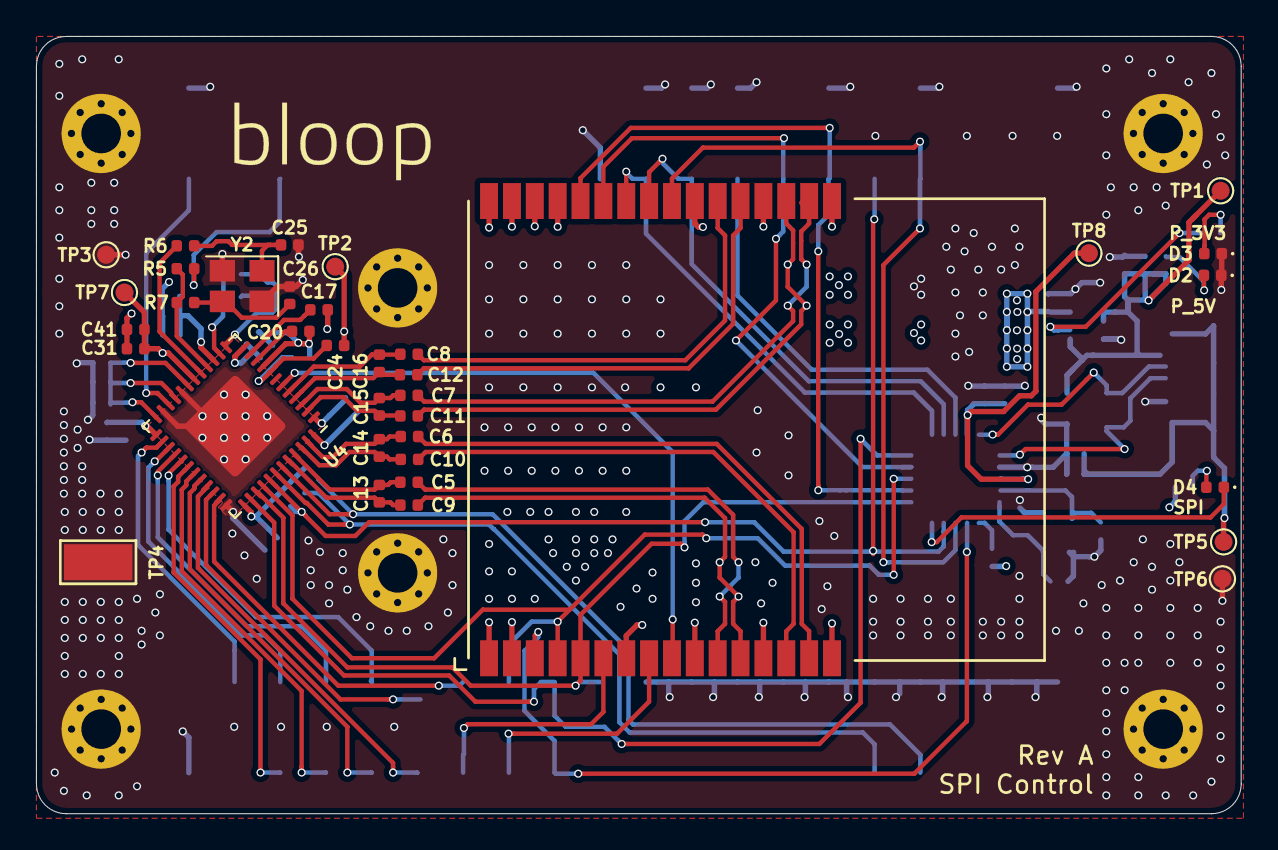
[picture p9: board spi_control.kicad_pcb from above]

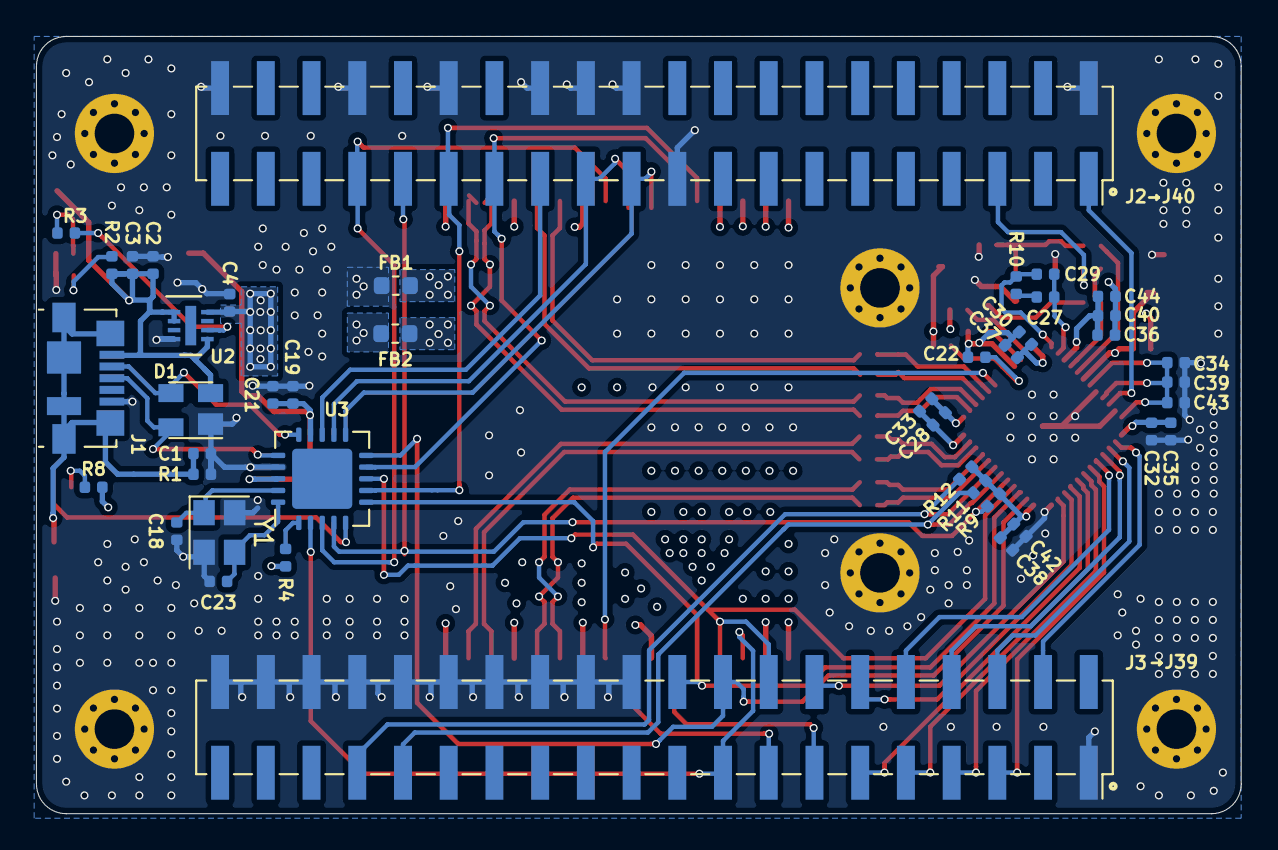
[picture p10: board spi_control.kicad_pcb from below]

Board: 4 copper layers, 66.9 x 43.2 mm, 85 parts (43 on the bottom side), 71 nets.

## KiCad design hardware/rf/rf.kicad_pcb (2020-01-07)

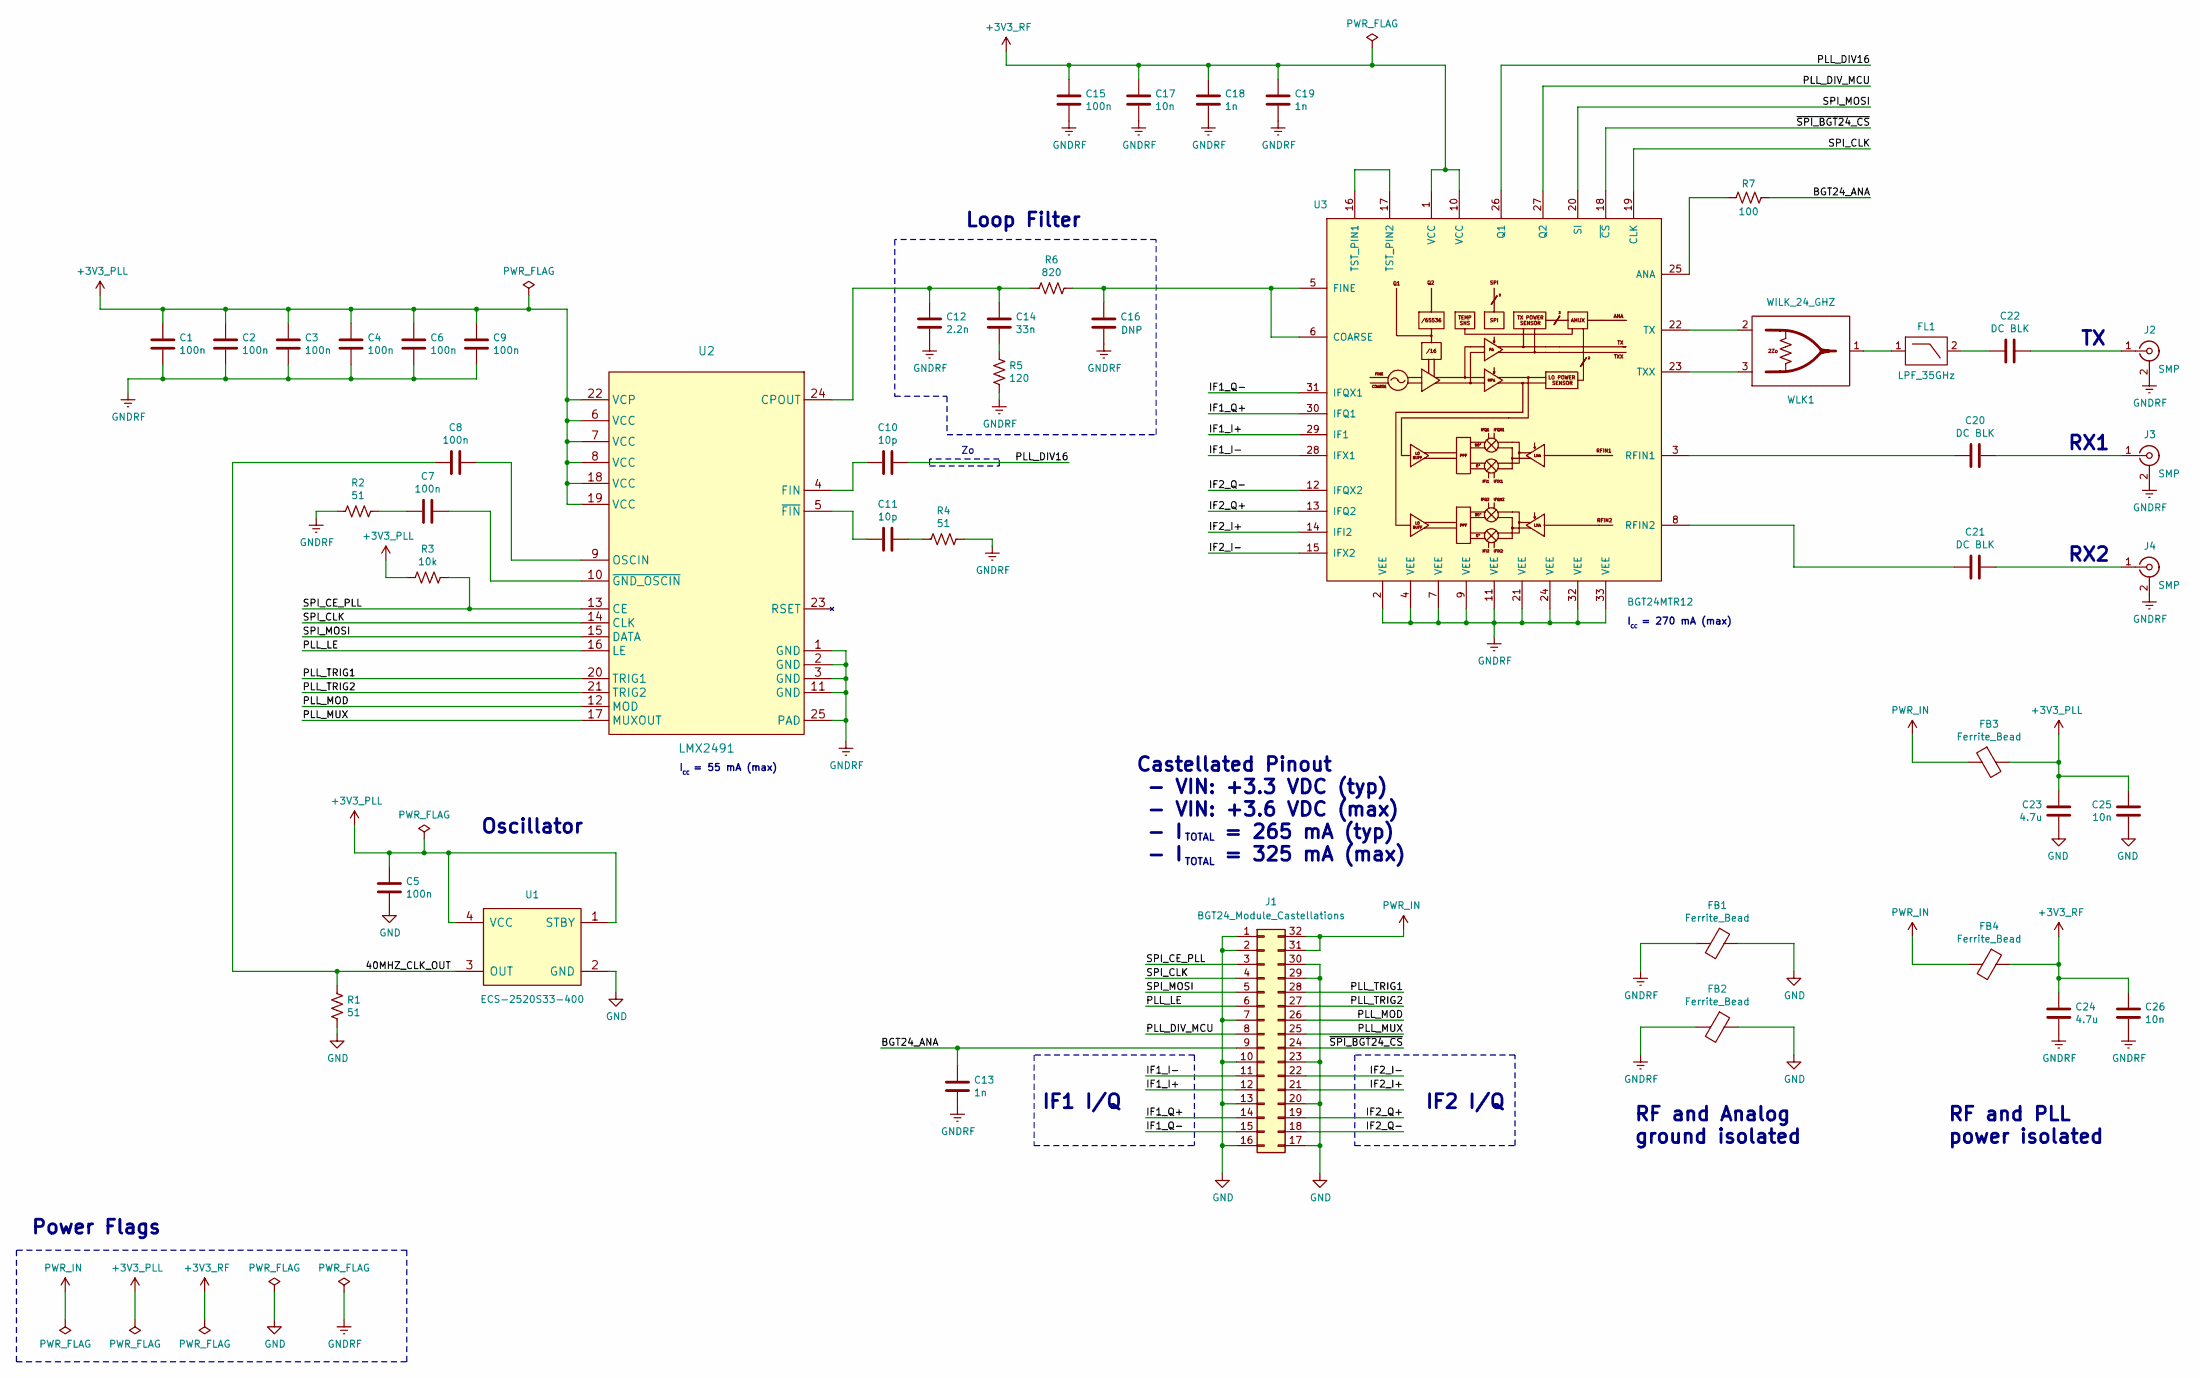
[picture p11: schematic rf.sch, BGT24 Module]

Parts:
C1, C2, C3, C4, C5, C6, C7, C8, C9, C15: 100n; C_0201_0603Metric; MPN GRM033R6YA104KE14D
C10, C11: 10p; C_0402_1005Metric; MPN GCM1555C1H100GA16D
C12: 2.2n; C_0201_0603Metric; MPN GRM033R61C223KE84D
C13, C18, C19: 1n; C_0201_0603Metric; MPN GRM033R71H102KA12D
C14: 33n; C_0201_0603Metric; MPN GRM033R61C333KE84D
C16: C_0201_0603Metric
C17, C25, C26: 10n; C_0201_0603Metric; MPN GRM033R71E103KE14D
C20, C21, C22: DC BLK; DC_Block
C23, C24: 4.7u; C_0603_1608Metric; MPN GRM188R61E475KE11D
FB1, FB2, FB3, FB4: Ferrite_Bead; L_0402_1005Metric; MPN MPZ1005S121CT000
FL1: LPF_35GHz; 35GHz_LPF
J1: BGT24_Module_Castellations
J2, J3, J4: SMP; 85305-0232; MPN 0853050232
R1, R2, R4: 51; R_0201_0603Metric; MPN ERJ-1GNF51R0C
R3: 10k; R_0201_0603Metric; MPN ERJ-1GNF1002C
R5: 120; R_0201_0603Metric; MPN ERJ-1GNJ121C
R6: 820; R_0201_0603Metric; MPN ERJ-1GNF8200C
R7: 100; R_0201_0603Metric; MPN ERJ-1GNF1000C
U1: ECS-2520S33-400; Crystal_SMD_2520-4Pin_2.5x2.0mm; MPN ECS-2520S33-400-FN-TR
U2: LMX2491; VQFN-24-1EP_4x4mm_P0.5mm_EP2.45x2.45mm; MPN LMX2491RTWR
U3: BGT24MTR12; MPN BGT24MTR12E6327XUMA1
WLK1: WILK_24_GHZ; Wilk_AWR_Mod

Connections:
+3V3_PLL: C1.1, C2.1, C3.1, C4.1, C5.1, C6.1, C9.1, C23.1, C25.1, FB3.2, R3.2, U1.1 (STBY), U1.4 (VCC), U2.6 (VCC), U2.7 (VCC), U2.8 (VCC), U2.18 (VCC), U2.19 (VCC), U2.22 (VCP)
+3V3_RF: C15.1, C17.1, C18.1, C19.1, C24.1, C26.1, FB4.1, U3.1 (VCC), U3.10 (VCC)
/40MHZ_CLK_OUT: C8.1, R1.1, U1.3 (OUT)
/BGT24_ANA: C13.1, J1.9, R7.1
/IF1_I+: J1.12, U3.29 (IF1)
/IF1_I-: J1.11, U3.28 (IFX1)
/IF1_Q+: J1.14, U3.30 (IFQ1)
/IF1_Q-: J1.15, U3.31 (IFQX1)
/IF2_I+: J1.21, U3.14 (IFI2)
/IF2_I-: J1.22, U3.15 (IFX2)
/IF2_Q+: J1.19, U3.13 (IFQ2)
/IF2_Q-: J1.18, U3.12 (IFQX2)
/PLL_DIV16: C10.1, U3.26 (Q1)
/PLL_DIV_MCU: J1.8, U3.27 (Q2)
/PLL_LE: J1.6, U2.16 (LE)
/PLL_MOD: J1.26, U2.12 (MOD)
/PLL_MUX: J1.25, U2.17 (MUXOUT)
/PLL_TRIG1: J1.28, U2.20 (TRIG1)
/PLL_TRIG2: J1.27, U2.21 (TRIG2)
/SPI_CE_PLL: J1.3, R3.1, U2.13 (CE)
/SPI_CLK: J1.4, U2.14 (CLK), U3.19 (CLK)
/SPI_MOSI: J1.5, U2.15 (DATA), U3.20 (SI)
/~SPI_BGT24_CS: J1.24, U3.18 (~CS)
GND: C5.2, C23.2, C25.2, FB1.1, FB2.1, J1.1, J1.2, J1.7, J1.10, J1.13, J1.16, J1.17, J1.20, J1.23, J1.29, J1.30, R1.2, U1.2 (GND)
GNDRF: C1.2, C2.2, C3.2, C4.2, C6.2, C9.2, C12.2, C13.2, C15.2, C16.2, C17.2, C18.2, C19.2, C24.2, C26.2, FB1.2, FB2.2, J2.2 (Ext), J3.2 (Ext), J4.2 (Ext), R2.2, R4.1, R5.2, U2.1 (GND), U2.2 (GND), U2.3 (GND), U2.11 (GND), U2.25 (PAD), U3.2 (VEE), U3.4 (VEE), U3.7 (VEE), U3.9 (VEE), U3.11 (VEE), U3.21 (VEE), U3.24 (VEE), U3.32 (VEE), U3.33 (VEE)
unnamed: C7.1, R2.1
unnamed: C7.2, U2.10 (~GND_OSCIN)
unnamed: C8.2, U2.9 (OSCIN)
unnamed: C10.2, U2.4 (FIN)
unnamed: C11.1, R4.2
unnamed: C11.2, U2.5 (~FIN)
unnamed: C12.1, C14.1, R6.2, U2.24 (CPOUT)
unnamed: C14.2, R5.1
unnamed: C16.1, R6.1, U3.5 (FINE), U3.6 (COARSE)
unnamed: C20.1, J3.1 (In)
unnamed: C20.2, U3.3 (RFIN1)
unnamed: C21.1, J4.1 (In)
unnamed: C21.2, U3.8 (RFIN2)
unnamed: C22.1, J2.1 (In)
unnamed: C22.2, FL1.2 (OUT)
unnamed: FL1.1 (IN), WLK1.1
unnamed: R7.2, U3.25 (ANA)
unnamed: U3.16 (TST_PIN1), U3.17 (TST_PIN2)
unnamed: U3.22 (TX), WLK1.2
unnamed: U3.23 (TXX), WLK1.3
PWR_IN: FB3.1, FB4.2, J1.31, J1.32

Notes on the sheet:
Loop Filter
Power Flags
Oscillator
I = 270 mA (max)
IF2 I/Q
RF and Analog ground isolated
Castellated Pinout - VIN: +3.3 VDC (typ) - VIN: +3.6 VDC (max) - I = 265 mA (typ) - I = 325 mA (max)
TOTAL
I = 55 mA (max)
RX1
RX2
IF1 I/Q
RF and PLL power isolated

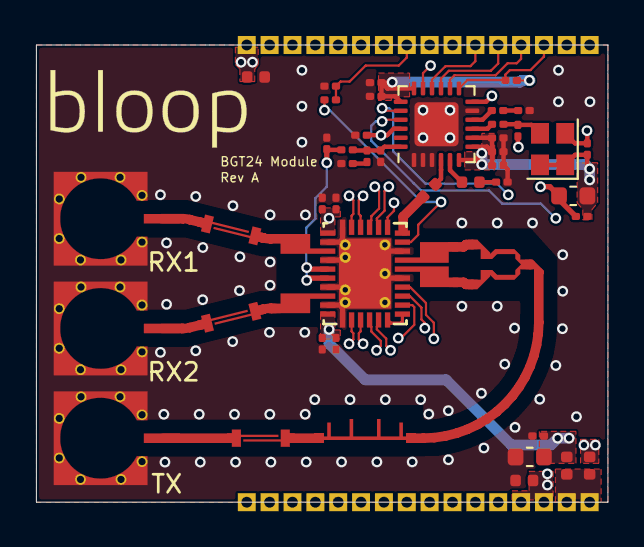
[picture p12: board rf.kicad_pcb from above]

Board: 4 copper layers, 31.8 x 25.4 mm, 46 parts (1 on the bottom side), 46 nets.

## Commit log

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2019-07-27 Added bloop schematic symbol library Added LPF_35GHz schematic symbol
    [bloop.sch]
2019-07-28 Added schematic hierarchial sheets
    [Baseband.sch, Interfaces.sch, Power.sch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]
2019-07-28 Radar MMIC symbol; Pcbnew worksheet template added to bloop.kicad_pcb
    [bloop.kicad_pcb]
2019-07-28 Added 3d SMP footprint and model
    [Radar_MMIC_RF_Front_End.sch, bloop.sch]
2019-07-28 Corrected 3d model path for SMP connector 0734153320
2019-07-28 Added BGT24MTR12 VQFN-32-9 footprint Updated gold material on 3d model 734153320
    [Radar_MMIC_RF_Front_End.sch, bloop.kicad_pcb, bloop.sch]
2019-07-28 Rearrange pins for aesthetic reasons
    [Radar_MMIC_RF_Front_End.sch]
2019-07-28 Add rev; add titles to schematic sheets
    [Baseband.sch, Interfaces.sch, Power.sch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]
2019-07-28 Move power sheet box
    [bloop.sch]
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2019-07-28 Started PLL circuitry Added PLL device and oscillator Still need loop filter and clock filter circuits
    [Baseband.sch, Interfaces.sch, Power.sch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]
2019-07-29 Add DC blocking capacitors; add larger resistor and capacitor symbols; implement root PN for symbols
    [Radar_MMIC_RF_Front_End.sch, bloop.sch]
2019-07-30 fixing MPNs
    [Radar_MMIC_RF_Front_End.sch]
2019-08-06 Add stubs to RX portion; move blocking caps
    [Baseband.sch, Interfaces.sch, Power.sch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]
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2019-08-25 Corrected Infineon Wilkinson footprint
2019-08-25 Added Taper 8 24Ghz wilk/matched on PCB
    Added Taper 8 24Ghz wilk/matched on PCB
    [front_end.sch]
2019-09-14 Started rough layout for panelization of front end pcbs
    [Baseband.sch, Interfaces.sch, Power.sch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]
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2019-09-15 Fixed keepouts on front end pcb layout
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2019-09-18 Incorporate template; remove temporary .sch-bak file; add bottom silk revision; remove unecessary filter half-sections; center align top silk.
    [front_end.sch]
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2019-09-22 Include modified AWR wilkinson design; need to correct chamfers and wilkinson line lengths
    [front_end.sch]
2019-09-27 Add bloop logo's; correct silkscreen; change to 0402 RF footprint; add wilkinson solder mask
    [front_end.sch]
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2019-09-28 Front end PCB layout edits and footprint modifications
    [front_end-B_Cu.gbl, front_end-B_Mask.gbs, front_end-B_SilkS.gbo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]
2019-09-28 DRC check and fixes on front end pcb layout
    [front_end-B_Cu.gbl, front_end-B_Mask.gbs, front_end-B_SilkS.gbo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]
2019-09-28 Final layout edits to front end pcb layout
    [front_end-B_Cu.gbl, front_end-B_Mask.gbs, front_end-B_SilkS.gbo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]
2019-09-28 Fix top silk alignment; fix 0402 RF cap mask
    [front_end-B_Cu.gbl, front_end-B_Mask.gbs, front_end-B_SilkS.gbo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]
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2019-10-06 Footprint 3d model fixes, and removed paste from microstrip filters
2019-10-11 Re-structure bloop folder hierarchy; create end-result pdfs of front_end; update relative paths.
    [Baseband.sch, Interfaces.sch, Power.sch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]
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2019-10-13 Added 3.3V LDO ST1L08SPU33R symbol. Completed power and SPI controller schematic sections
    [spi_control.sch]
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2019-10-14 Corrected ~SPI_PLL_CS to PLL_LE and changed value of U1 to display the complete MPN
    [rf.sch]
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2019-10-15 Directory restructuring to match master and updated symbol and footprint references
    [front_end-B_Cu.gbl, front_end-B_Mask.gbs, front_end-B_SilkS.gbo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]
2019-10-17 Added BGT24 module castellation footprint, 3d model for 40MHz XO. Edits to schematic and pinouts based on layout of module. Initial parts placement and routing complete.
    [rf.kicad_pcb, rf.sch]
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2019-10-18 Replaced TH SMP connectors with SMT
    [rf.kicad_pcb, rf.sch]
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2019-10-19 Copied the SP0503BA digikey symbol to project library and replaced in schematic
    [spi_control.sch]
2019-10-20 Add 30 mil mask; update schematic for connector orientation
    [rf.kicad_pcb, rf.sch]
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2019-10-26 BGT24 module layout of PLL and via stitching
    [rf.kicad_pcb]
2019-10-28 BGT24 module final draft layout. Ready for review
    [rf.kicad_pcb, rf.sch]
2019-10-28 Generated schematic pdf and FAB files for review of revA BGT24 Module
    [rf-B_Cu.gbr, rf-B_Mask.gbr, rf-B_SilkS.gbr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]
2019-10-30 Layout review edits with Austin. Added BGT24 Module FAB files and started the panel for the module
    [rf-B_Cu.gbr, rf-B_Mask.gbr, rf-B_SilkS.gbr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]
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2019-11-01 Assigned MPNs to components and generated BOM. Small layout edits for changed part footprints
    [rf-B_Cu.gbr, rf-B_Mask.gbr, rf-B_SilkS.gbr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]
2019-11-04 Added basic 3d model for BGT24 Module footprint. Final edits to layout and panel layout. Updated FAB files for each.
    [rf-B_Cu.gbr, rf-B_Mask.gbr, rf-B_SilkS.gbr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]
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2019-11-05 Updated BGT24 Module layout and panel with new castellation footprint and adjusted some vias. Re-generated FAB outputs.
    [rf-B_Cu.gbr, rf-B_Mask.gbr, rf-B_SilkS.gbr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]
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2019-11-05 Fixed AUX axis on panel layout and regenerated FAB files.
    [rf_panel-B_Cu.gbr, rf_panel-B_Mask.gbr, rf_panel-B_SilkS.gbr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]
2019-11-06 Include -rescue ignore from master anddelete -rescue byproducts; bring in BGT24 module symbols/footprints from master and add relevant 3D models; beautify spi_control.sch
    [spi_control.sch]
2019-11-07 Official BGT24 Module Rev A release. Updated README.md, BGT24 Module schematic title and added 3d render of BGT24 Module PCB. Created an 'outputs' folder for PDF schematic and renders.
    [rf.sch]
2019-11-09 Finished connector mapping for ECP5 devboard. Versa Connector.
    [spi_control.kicad_pcb, spi_control.sch]
2019-11-09 Fixed 3D Model path for the RF castelation board. Added mounting holes for antenna secure.
    [spi_control.kicad_pcb]
2019-11-10 Aligned all holes to by symmetric and locked their position
    [spi_control.kicad_pcb]
2019-11-10 Found error in layer stackup, fixed net for top copper.
    [spi_control.kicad_pcb]
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2019-11-10 Started routing SPI to USB. Started preliminary routing for the IQ data.
    [spi_control.kicad_pcb, spi_control.sch]
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2019-11-10 Completed power section, completed analog power and gnd plane,fixed IQ lines to be symmetric, ADC 80% routing completed.
    [spi_control.kicad_pcb, spi_control.sch]
2019-11-10 Optimized ADC bit routing, moved nets around for J39.
    [spi_control.kicad_pcb]
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2019-11-16 Fixed gnd patch on ADAR ADC footprint
    [spi_control.kicad_pcb]
2019-11-16 Added 3d model for ADAR7251 and moved footprint into bloop.pretty. Updated schematic, J39-13 swaped with J39-15. Corrected stackup text in layout to ECO1 layer from BCu.
    [spi_control.kicad_pcb, spi_control.sch]
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2019-11-16 Found mistake in header breakout, grounds were not connected. Fixed, layout and schematic.
    [spi_control.kicad_pcb, spi_control.sch]
2019-11-18 Remove Dime scale. Fill on Top layer has no net. GND Fill on Bottom layer has no net. GND Schematic: Clean up the ground connections on J40, J39, Y2, and Y1. Schematic: Remove ECP5 eval board schemat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
    [spi_control-B_Cu.gbr, spi_control-B_Mask.gbr, spi_control-B_Paste.gbr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]
2019-11-21 Tented the vias on the BGT24 module and the BGT24 module panel FAB files. This fixes #25
    [rf-B_Cu.gbr, rf-B_Mask.gbr, rf-B_SilkS.gbr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]
2019-12-27 Nov 17 Issues 1-22 complete.
    [spi_control.kicad_pcb, spi_control.sch]
2019-12-27 All issues EXCEPT 6,22,23 complete.
    [spi_control.sch]
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2020-01-04 Generated HTML bom, Issue 6 resolved.
2020-01-04 Resolve 4, 11, 16, 18, and 25 from #24 and includes misc. improvements
    [spi_control.kicad_pcb, spi_control.sch]
2020-01-05 Resolve 9 from #24; added some vias to layout and moved a few tracks
    [spi_control.kicad_pcb, spi_control.sch]
2020-01-05 Finalize BOM, finish schematic annotations, re-generate gerbers. Close #24
    [spi_control-B_Cu.gbr, spi_control-B_Mask.gbr, spi_control-B_Paste.gbr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]
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2020-01-07 Change to protel gerber extensions; update HTML BOM; update sch/pcb PDF outputs
    [rf-B_Cu.gbl, rf-B_Cu.gbr, rf-B_Mask.gbr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]
2020-01-12 Created a Fab Spin folder for the recent order
    [JLC_DNP.xlsx, spi_control-bottom-_JLCSMTBOM.xlsx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]
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
